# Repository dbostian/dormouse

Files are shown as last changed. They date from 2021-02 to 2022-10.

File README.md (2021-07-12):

# Dormouse
## An Alix/Prime-E Inspired 40% Mechanical Keyboard

example

example

example

A 3d-printable 40% keyboard, for the handwired mechanical keyboard crowd. It fits on a larger (250mm wide) print bed without having to split the shell or plate.

[Keyboard Layout Editor Permalink](http://www.keyboard-layout-editor.com/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,%3B&@_r:-3&rx:4.5&ry:1.25&y:4.25&x:8.13&w:1.25%3B&=Super)

## Project Structure
**/stls** - STL files for 3d Printing

**/qmk** - Firmware folder for QMK

**/raw_data** - Data from [keyboard-layout-editor.com](http://www.keyboard-layout-editor.com/) and [kbfirmware.com](https://kbfirmware.com/)

**default.hex** - Compiled firmware, for flashing.

## Layers
"So, how do you type on this thing?" "Where are the numbers?" "Don't you need arrow keys?"

example
To access other keys like numbers, the F row, the arrows, you need to hold down a modifier key to access various layers. The layers I user are Nav (arrow keys, page up, home, end etc.), Num (1-10, +, -, =), Symbol (!, @, %, #, etc.) and Fn (F1-F12, Print Screen).

example
The Nav layer turns WASD into the arrow cluster, and also houses the other navigation keys. This key is easy to hit with the left thumb, so it is also used for some of the keys that that were removed from the right side of the board (quotes, semicolon, slashes). It also turns escape into the tilde.

example
The Num layer simply houses the numbers, along with the = and - keys.

example
The Symbol layer is like the number layer plus shift, so you don't have to create a 3-key combo for those characters. The Symbol layer key doubles as a second space bar. Tap it for a space, hold it down to switch layers.

example
The Fn layer gives access to F1-F12, plus some lesser-used keys, like caps lock and print screen. I've also placed the RGB controls on this layer, along with the all-important RESET key for flashing new firmware.

## Mouse Keys (Alternate Layout)

example
**Update:** I've added a second keymap with Mouse Keys layer for use in an upcoming project. This is achieved using Mod Tap on the left spacebar, similar to the Symbol layer. Tap for space, hold for mouse. WASD is mouse movement, J/K is left/right click, and Y/H is the scroll wheel. I realize this is not for everyone's taste, so there's a separate firmware (**mouse.hex**) containing this keymap. I picked button locations that seemed natural for me, but if you would like to customize the mouse buttons, the new **/mouse/keymap.c** layout is included in the **qmk** folder... along with the **config.h** for governing mouse behavior (acceleration, max speed, etc).

[https://beta.docs.qmk.fm/using-qmk/advanced-keycodes/feature_mouse_keys](https://beta.docs.qmk.fm/using-qmk/advanced-keycodes/feature_mouse_keys)

## Construction

### Printed Parts
- [ ] 1x Plate
- [ ] 1x Shell
- [ ] 1x MCU Tray

### Hardware
- [ ] Keycaps
- [ ] 44x Switches (cherry compatable)
- [ ] 44x 1N4148 Diodes
- [ ] 1x Pro Micro
- [ ] 2x 2u Costar Stabilizers (optional)
- [ ] 7x WS2812 RGB Leds (optional)
- [ ] 15x M3 x 8mm Countersunk Machine Screw
- [ ] Wire
- [ ] VHB or other double-stick tape

### Tools / Misc
- [ ] 3d Printer + Filament
- [ ] Soldering Iron + Solder
- [ ] Multimeter
- [ ] Wire Cutters / Strippers / Flush Cutters
- [ ] Hex Drivers
- [ ] M3 Tap

### Printing Notes
The plate and shell will fit on a 250mm wide print bed, but only just. You will need to turn off any skirt or brim in order to make it fit.

Print at 0.2mm layer height. To create the embossed teacup in the bottom of the shell, use the color changing feature in your slicing software. Print the first layer in black, then change filament color for the remainder of the print. I suggest translucent.

example

### Wiring
Rows are wired to pins F4, F5, F6, and F7. Columns are wired to B1, B3, B2, B6, B5, B4, E6, D7, C6, D4, D0, and D1. The RGB LED strip is wired to D3.

example

example

### Assembly
Tap appropriate holes in the shell and mcu tray to M3. Insert all switches into plate. Align the MCU tray with Q key/hole in the shell, and stick the Pro Micro down with VHB. Solder rows and columns according to the excellent [QMK Hand Wiring Guide](https://beta.docs.qmk.fm/using-qmk/guides/keyboard-building/hand_wire). Arrange wires neatly, and attach the  mcu and then plate to shell with M3x8mm countersunk screws - use caution to not overtighten and strip the threads. Install keycaps.

### Firmware
I use [QMK firmware](https://qmk.fm/). The **default.hex** file contains the keymap as described above. There's an included **/keyboards** folder for customizing your own keymap using QMK, or you can upload the **raw_data/kbfirmware.json** to [kbfirmware.com](https://kbfirmware.com/).

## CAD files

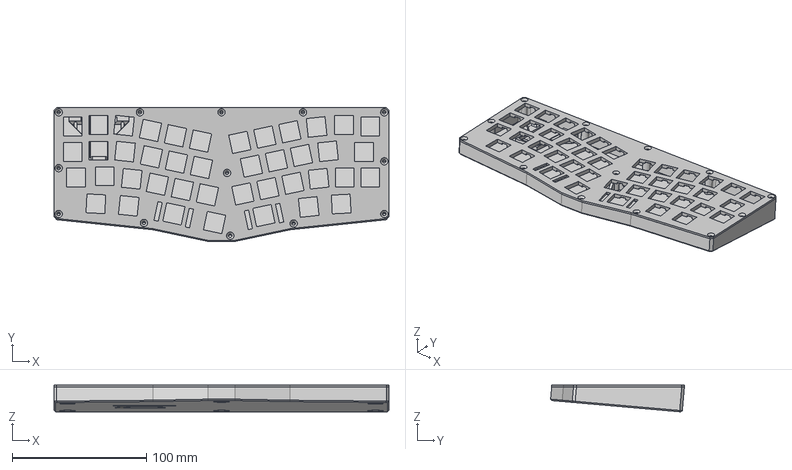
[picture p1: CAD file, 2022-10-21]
steps/dormouse.step
249.5 x 99.7 x 20.0 mm
Plate
IO Shield
Tray2

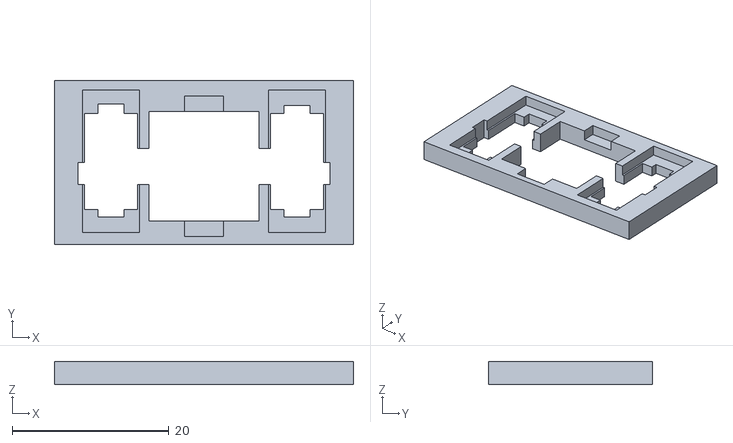
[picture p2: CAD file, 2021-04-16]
stls/plate_cherry_test.stl
38.2 x 21.0 x 3.00

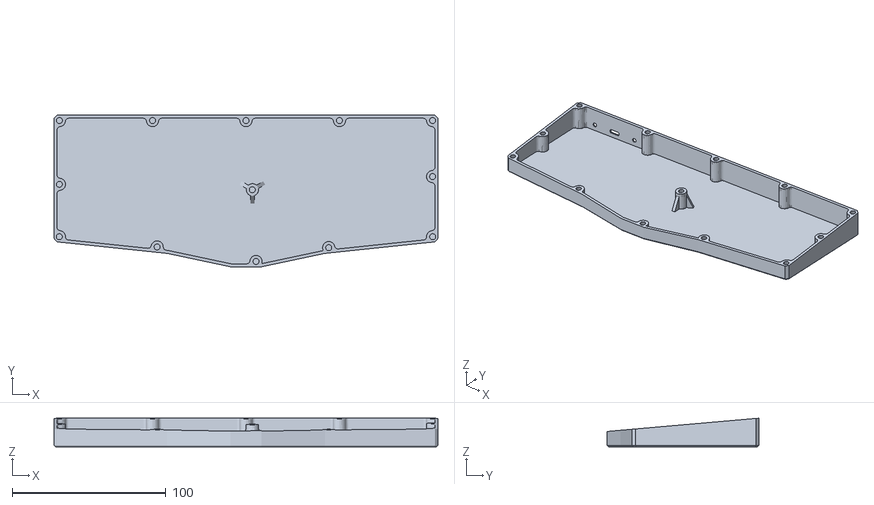
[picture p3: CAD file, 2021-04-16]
stls/shell_insert_version.stl
249.5 x 98.5 x 18.6

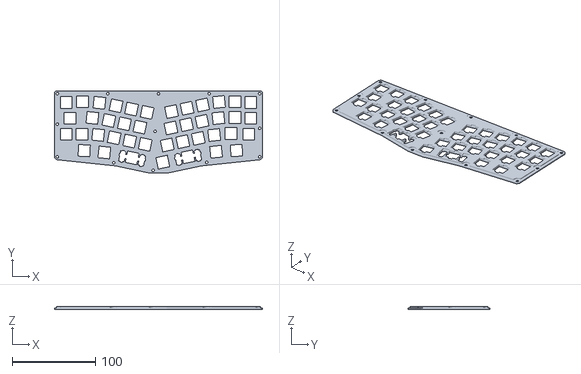
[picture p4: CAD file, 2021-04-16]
stls/plate_cherry_version.stl
249.5 x 98.9 x 3.00

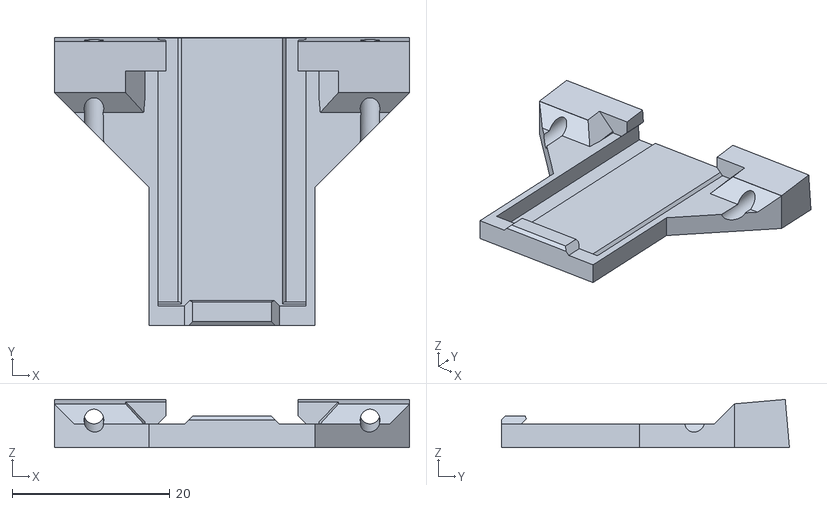
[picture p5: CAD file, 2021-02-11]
stls/tray.stl
45.0 x 36.5 x 6.11

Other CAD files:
stls/plate.stl
stls/shell.stl

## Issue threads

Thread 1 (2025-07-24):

Not an issue, but a thank you!

kvorschk, 2025-07-24:
I really couldn't find another way to message you so I am trying this. I hope it doesn't bother you. But I wanted to thank you. I came across your board on a keyboard site and decided to try it out. I have been using it since and am currently building a second for my other computer. I truly love typing on this thing!

Closed 2025-07-24.

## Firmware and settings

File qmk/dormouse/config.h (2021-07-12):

#ifndef CONFIG_H
#define CONFIG_H

#include "config_common.h"

/* USB Device descriptor parameter */
#define VENDOR_ID       0xFEED
#define PRODUCT_ID      0x6060
#define DEVICE_VER      0x0001
#define MANUFACTURER    qmkbuilder
#define PRODUCT         keyboard
#define DESCRIPTION     Keyboard

/* key matrix size */
#define MATRIX_ROWS 4
#define MATRIX_COLS 12

/* key matrix pins */
#define MATRIX_ROW_PINS { F4, F5, F6, F7 }
#define MATRIX_COL_PINS { B1, B3, B2, B6, B5, B4, E6, D7, C6, D4, D0, D1 }
#define UNUSED_PINS

/* COL2ROW or ROW2COL */
#define DIODE_DIRECTION COL2ROW

/* number of backlight levels */

#ifdef BACKLIGHT_PIN
#define BACKLIGHT_LEVELS 5
#endif

/* Set 0 if debouncing isn't needed */
#define DEBOUNCING_DELAY 5

/* Mechanical locking support. Use KC_LCAP, KC_LNUM or KC_LSCR instead in keymap */
#define LOCKING_SUPPORT_ENABLE

/* Locking resynchronize hack */
#define LOCKING_RESYNC_ENABLE

/* key combination for command */
#define IS_COMMAND() ( \
    keyboard_report->mods == (MOD_BIT(KC_LSHIFT) | MOD_BIT(KC_RSHIFT)) \
)

/* prevent stuck modifiers */
#define PREVENT_STUCK_MODIFIERS

#define RGB_DI_PIN D3
#ifdef RGB_DI_PIN
#define RGBLIGHT_ANIMATIONS
#define RGBLED_NUM 7
#define RGBLIGHT_HUE_STEP 8
#define RGBLIGHT_SAT_STEP 8
#define RGBLIGHT_VAL_STEP 8
#endif

/* Mouse Keys */
#define MOUSEKEY_INTERVAL 16
#define MOUSEKEY_DELAY 0
#define MOUSEKEY_TIME_TO_MAX 60
#define MOUSEKEY_MAX_SPEED 7
#define MOUSEKEY_WHEEL_DELAY 0

#endif

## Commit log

2021-03-23 Repaired plate stl
    [plate.stl]
2021-03-24 Meshmixer patched plate stl.
    [plate.stl]
2021-03-25 Reduced complexity of plate stl
    [plate.stl]
2021-04-16 Added additional stls for cherry stabilizers, heatset inserts
    [plate_cherry_version.stl, shell_insert_version.stl]
2021-04-16 Added cherry profile test print
    [plate_cherry_test.stl]
2021-04-16 STL orientation
    [plate_cherry_test.stl, plate_cherry_version.stl, shell_insert_version.stl]
2022-10-21 Added step file
    [dormouse.step]
